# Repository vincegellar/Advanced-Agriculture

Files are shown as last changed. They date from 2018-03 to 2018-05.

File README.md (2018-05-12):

# Advanced Agriculture

**_Warning: The project is still in early development, so expect some features and documentation to be missing, or not work correctly._**

## What is this all about?
Use a Raspberry PI to monitor, and care for your plants. Connect the sensors to NodeMCUs to connect many plants to one Raspberry.

## Features:
- Automated Watering
- Automated Light Provisioning
- E-mail warnings
- Web Statistics
- Set Dark Hours
- Set Silent Hours

## Hardware:
- Raspberry PI 3 Model B / Raspberry PI Zero W
- NodeMCU ESP8266 / ESP32

### Sensors:
- Temperature & Humidity: DHT11
- Soil Moisture
- Light Inensity: BH1750FVI
- Water Level In The Tank

### Actuators:
- 12V Submersible Pump
- Full Spectrum 10W Pink LED

## How to install?
Run the following on the Raspberry PI:
```bash
curl -s https://raw.githubusercontent.com/vincegellar/Advanced-Agriculture/master/install.sh | bash
```

## License:

Advanced Agriculture: A plant automation IoT system.
    Copyright (C) 2018  Viktor Bán (viktor.ban@gmail.com), Vince Gellár (gellar.vince@gmail.com)

    This program is free software: you can redistribute it and/or modify
    it under the terms of the GNU General Public License as published by
    the Free Software Foundation, either version 3 of the License, or
    (at your option) any later version.

    This program is distributed in the hope that it will be useful,
    but WITHOUT ANY WARRANTY; without even the implied warranty of
    MERCHANTABILITY or FITNESS FOR A PARTICULAR PURPOSE.  See the
    GNU General Public License for more details.

    You should have received a copy of the GNU General Public License
    along with this program.  If not, see <http://www.gnu.org/licenses/>.

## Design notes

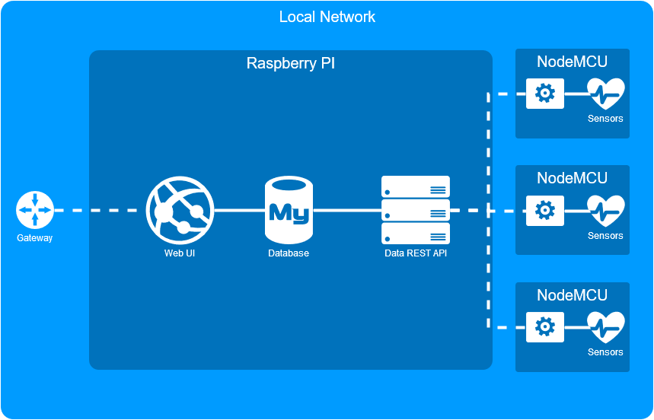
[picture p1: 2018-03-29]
Wiki/overview.png

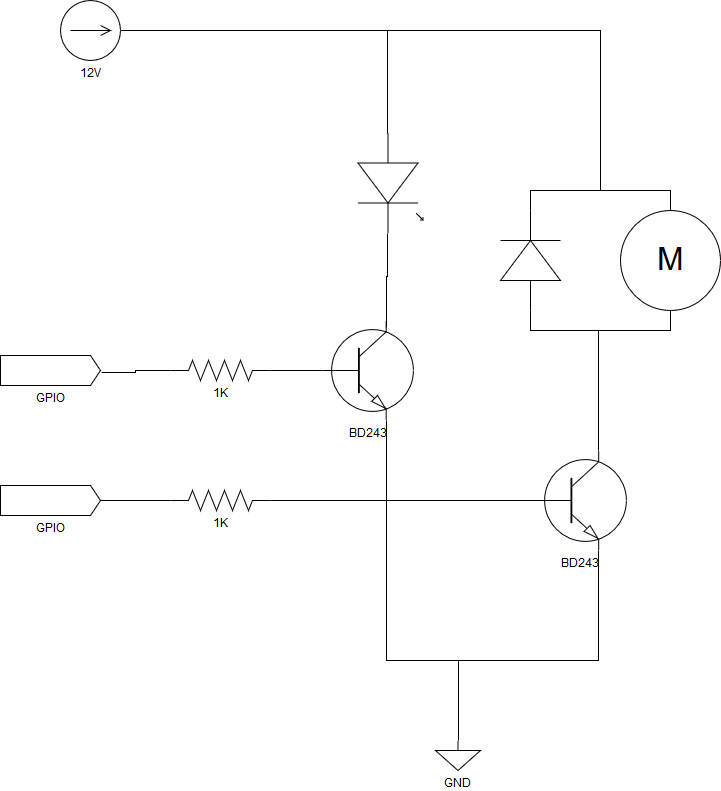
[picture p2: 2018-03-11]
Wiki/switch.png

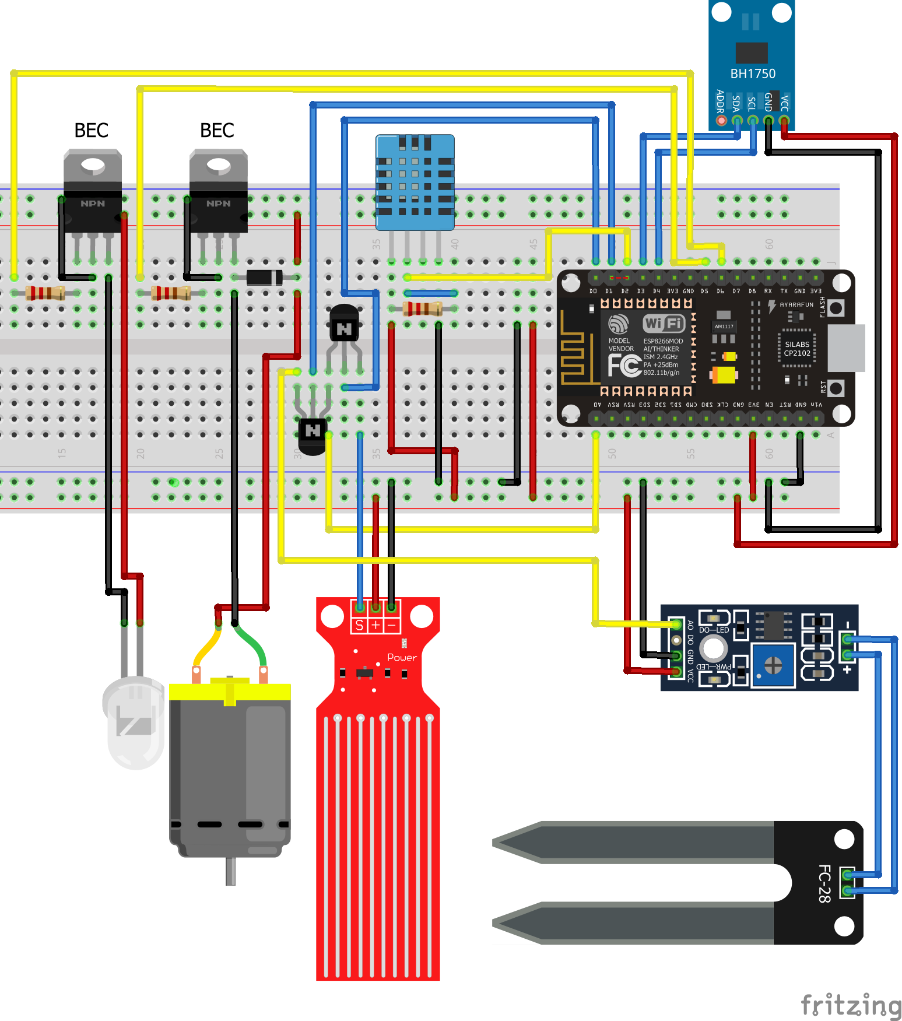
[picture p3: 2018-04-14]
Wiki/ESP8266.png

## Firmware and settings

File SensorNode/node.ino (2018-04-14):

#include <ArduinoJson.h>
#include <BH1750.h>
#include <DHTesp.h>
#include <ESP8266HTTPClient.h>
#include <ESP8266WiFi.h>
#include <WiFiUdp.h>
#include <Wire.h>

#define SERIAL_BAUDRATE 115200
#define PIN_WATER_SOIL A0
#define PIN_WATER_SELECT D0
#define PIN_SOIL_SELECT D1
#define PIN_DHT D2
#define PIN_SDA D3
#define PIN_SCL D4
#define PIN_PUMP D5
#define PIN_LIGHT D6

#define WATER_0 200
#define WATER_100 500
#define SOIL_0 700
#define SOIL_100 200

#define ANNOUNCE_PORT 44460
#define CONTROLLER_PORT 8080

typedef struct Measurement {
  uint16_t light;
  uint8_t waterLevel;
  uint8_t soilMoisture;
  int8_t temperature;
  uint8_t humidity;
} Measurement;

DHTesp dht;
WiFiUDP udp;
HTTPClient http;
BH1750 lightMeter;
Measurement lastMeasurement;
char controllerIp[16] = {0};
StaticJsonBuffer<256> jsonBuffer;
int plantId;
bool water = false;
unsigned long waterStop;

void setup() {
  Serial.begin(SERIAL_BAUDRATE);

  // Initialize hardware
  Wire.begin(PIN_SCL, PIN_SDA);
  pinMode(PIN_WATER_SOIL, INPUT);
  pinMode(PIN_WATER_SELECT, OUTPUT);
  pinMode(PIN_SOIL_SELECT, OUTPUT);
  pinMode(PIN_PUMP, OUTPUT);
  pinMode(PIN_LIGHT, OUTPUT);
  dht.setup(PIN_DHT);
  lightMeter.begin();

  connectWifi("", "");
  detectController();
  configureNode();

  Serial.println("MAC:        " + WiFi.macAddress());
  Serial.print  ("IP:         "); Serial.println(WiFi.localIP());
  Serial.printf ("Controller: %s\n", controllerIp);
  Serial.printf ("Plant ID:   %d\n", plantId);

  Serial.println("Setup done\n\n");
}

uint8_t loopCounter = 0;
void loop() {
  if (water && millis() >= waterStop) water = false;
  digitalWrite(PIN_PUMP, water ? HIGH : LOW);

  // Send measurements every 2 seconds
  if (++loopCounter >= 20) {
    lastMeasurement = measure();
    Serial.printf("Water level:   %d %%\n", lastMeasurement.waterLevel);
    Serial.printf("Soil moisture: %d %%\n", lastMeasurement.soilMoisture);
    Serial.printf("Light:         %d lx\n", lastMeasurement.light);
    Serial.printf("Temperature:   %d C\n", lastMeasurement.temperature);
    Serial.printf("Humidity:      %d %%\n", lastMeasurement.humidity);
    Serial.print("\n\n");
    upload(lastMeasurement);
    loopCounter = 0;
  }
  
  delay(100);
}

void connectWifi(const char* ssid, const char* password) {
  WiFi.mode(WIFI_STA);
  WiFi.begin(ssid, password);
  Serial.print("Connecting to WiFi ");
  while (WiFi.status() != WL_CONNECTED) {
    Serial.print(".");
    delay(1000);
  }
  Serial.println("");
}

void detectController() {
  udp.begin(ANNOUNCE_PORT);
  Serial.print("Detecting controller ");
  while (controllerIp[0] == 0) {
    Serial.print(".");
    int packetSize = udp.parsePacket();
    if (packetSize) {
      IPAddress ip = udp.remoteIP();
      sprintf(controllerIp, "%d.%d.%d.%d", ip[0], ip[1], ip[2], ip[3]);
      udp.stop();
    }
    delay(1000);
  }
  Serial.println("");
}

void configureNode() {
  char data[32];
  String mac = WiFi.macAddress();
  mac.replace(":", "");
  mac.toLowerCase();
  sprintf(data, "mac_address=%s", mac.c_str());  
  post("/configure", data, configureNodeSuccess);
}

void configureNodeSuccess(JsonObject& root) {
  plantId = root["plant_id"].as<int>();
}

void upload(Measurement m) {
  char data[128];
  sprintf(
    data, 
    "id=%d&water=%d&temperature=%d&humidity=%d&light=%d&moisture=%d",
    plantId,
    m.waterLevel,
    m.temperature,
    m.humidity,
    m.light,
    m.soilMoisture
  );
  post("/", data, uploadSuccess);
}

void uploadSuccess(JsonObject& root) {
  int waterTime = root["water_time"];
  bool lightOn = root["light_on"];
  
  if (waterTime > 0) {
    water = true;
    waterStop = millis() + waterTime * 1000;
  } else {
    water = false;
  }
  digitalWrite(PIN_LIGHT, lightOn ? HIGH : LOW);
}

void post(const char* path, char* data, void (*onSuccess)(JsonObject&)) {
  char url[64];
  sprintf(url, "http://%s:%d%s", controllerIp, CONTROLLER_PORT, path);
  http.begin(url);
  http.addHeader("Content-Type", "application/x-www-form-urlencoded");
  int httpStatus = http.POST(data);
  if (httpStatus == HTTP_CODE_OK) {
    onSuccess(jsonBuffer.parseObject(http.getString()));
  } else {
    Serial.printf("[HTTP] POST %s failed, error: %s\n", path, http.errorToString(httpStatus).c_str());
  }
  http.end();
}

Measurement measure() {
  Measurement m;

  digitalWrite(PIN_WATER_SELECT, HIGH);
  digitalWrite(PIN_SOIL_SELECT, LOW);
  m.waterLevel = max(0, min(100, (int) map(analogRead(PIN_WATER_SOIL), WATER_0, WATER_100, 0, 100)));
  digitalWrite(PIN_WATER_SELECT, LOW);
  digitalWrite(PIN_SOIL_SELECT, HIGH);
  m.soilMoisture = max(0, min(100, (int) map(analogRead(PIN_WATER_SOIL), SOIL_0, SOIL_100, 0, 100)));
  m.light = lightMeter.readLightLevel();
  m.temperature = dht.getTemperature();
  m.humidity = dht.getHumidity();

  return m;
}

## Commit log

2018-03-01 Create sensor service python project
2018-03-07 Read light intensity, temperature, humidity and soil moisture
2018-03-10 12V switch schematic
2018-03-11 Update switch design
2018-03-24 Data collection server (#1)
    Create data collection server.
    [EnvironmentHandler.cfg]
2018-03-25 Announcer on background thread (#7)
    Add local network announcer
    [EnvironmentHandler.cfg]
2018-04-12 Update README.md
    Remove direct PI connection, since the PI can't handle analog input without an external ADC, in which case it would only make the project more complicated, and not save on cost, since ESP8266s are re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
2018-04-14 ESP8266 schematic
    [ESP8266.fzz]
2018-04-14 Added transistor pin note
    [ESP8266.fzz]
2018-04-14 PoC ESP8266 code (#14)
    * PoC ESP8266 code
    * Calibrate sensors
    * Change controller port to 8080
2018-05-12 Simplify installation using a Bash script (#21)
    * Backend setup
    * Install Node & Yarn
    * Create upstart service
    * Fix based on real run
    [EnvironmentHandler.cfg]
